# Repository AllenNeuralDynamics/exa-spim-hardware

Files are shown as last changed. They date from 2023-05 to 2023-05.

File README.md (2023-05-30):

# exa-spim-hardware
Hardware files for the ExA-SPIM microscope system

## Description
This repository contains CAD (Solidworks) files for the ExA-SPIM microscope system. Files are organized in directories for each vendor, with subassemblies for various parts of the microscope. A bill of materials (BOM) is also provided.

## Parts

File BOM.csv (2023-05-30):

ITEM NO. | PART NUMBER | DESCRIPTION | QTY.
1 | table_B3648G |  | 1
2 | rail_XT95-1000 |  | 2
3 | rail_XT95-500 |  | 4
4 | rail_clamp_XT95P13 |  | 10
5 | rail_plate_XT95EC1 |  | 6
6 | post_RS6 |  | 4
7 | post_RS1P |  | 4
8 |  |  | 1
9 | board_L490 |  | 1
10 | rail_carriage_XT95RC1 |  | 11
11 |  |  | 1
12 | veo_lens |  | 1
13 | veo_VJD5.0X-151M-X-Y T_V14 |  | 1
14 | clamp_PF85B |  | 1
15 | post_RSH1.5 |  | 1
16 | rail_plate_XT95P12 |  | 3
17 | post_RS3 |  | 5
18 | rail_positioner_XT95N |  | 1
19 | adapter_VJD5.0X MODULE_VNP-604MX_ADAPTER |  | 1
20 | chamber |  | 1
21 | filter |  | 1
22 | ring_SM45RR |  | 1
23 | window |  | 1
24 | window_66191 |  | 1
25 | ring_SM2RR |  | 1
26 | 2958N16 | Sealing Plug | 2
27 | 7610N136 | Universal-Thread Push-to-Connect Tube Fitting | 1
28 | 3-290845 |  | 1
29 | 3-290846 |  | 1
30 | 3-290847 |  | 1
31 | 3-292353 |  | 1
32 | 3-292316 |  | 1
33 | 8-7711 |  | 3
34 | navitar_cap |  | 1
35 | navitar_adapter |  | 1
36 | navitar_window |  | 1
37 | kinematic_KCB2EC |  | 3
38 | cage_LCP30 |  | 2
39 | cage_LCP01 |  | 5
40 | kinematic_CXY2 |  | 6
41 | cage_LCP33 |  | 1
42 | kinematic_KCB1EC |  | 3
43 | kinematic_CXY1A |  | 1
44 | mirror_BBE1-E02 |  | 3
45 | mirror_BBE2-E02 |  | 3
46 | cage_LCP08 |  | 2
47 | lens_ACT508-300-A-ML |  | 1
48 | plate_CP08 |  | 1
49 | iris_SM1D12C |  | 1
50 | cage_CP33 |  | 1
51 | rod_ER2 |  | 12
52 | rod_ER12 |  | 12
53 | post_PH2 |  | 5
54 | post_TR3 |  | 4
55 | post_PH1.5 |  | 2
56 | post_TR1 |  | 4
57 | post_PH1 |  | 3
58 | tube_SM2L05 |  | 1
59 | lens_ACT508-200-A |  | 1
60 | post_TR1.5 |  | 1
61 | rod_ER6 |  | 12
62 | rod_ER3 |  | 4
63 | mount_SM1P1 |  | 1
64 | mount_SM2A6 |  | 1
65 | etl_EL-16-40-TC-VIS-20D-C |  | 1
66 | mount_LRM1 |  | 1
67 | mount_SM1A11 |  | 1
68 | mount_SM1T2 |  | 1
69 | Shibuya_HLB_5X |  | 1
70 | mount_SM1A27 |  | 1
71 | post_PH3 |  | 1
72 | post_TR4 |  | 1
73 | post_TR2 |  | 1
74 | mount_AP90L |  | 2
75 | galvo_QS20Y-AG |  | 2
76 | clamp_BA1S |  | 2
77 | rotation_mount_C60-3060-SRS |  | 1
78 | adapter_SM1A10 |  | 1
79 | tube_SM1L05E |  | 1
80 | adapter_SM2A21 |  | 1
81 | galvo_clamp_1 |  | 2
82 | galvo_clamp_2 |  | 2
83 | post_PH30_M |  | 2
84 | lens_LJ1695RM |  | 1
85 | stage_MS-8000 |  | 1
86 | stage_LS-100-FTP |  | 2
87 | insert_I-8001 |  | 1
88 | sample_base_0284-200-04 | Mounting cube bottom base | 1
89 | sample_wall_0284-200-01 | Mounting cube side wall #1 | 2
90 | sample_wall_0284-200-02 | Mounting cube side wall #2 | 2
91 | sample_lid_0284-200-03 | Mounting cube top | 1
92 | u_mount_0284-100-01 |  | 1

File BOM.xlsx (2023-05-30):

ITEM NO. | SOLIDWORKS PART NUMBER | CATALOG | CATALOG PART NUMBER | DESCRIPTION | QTY.
1 | table_B3648G | Thorlabs | B3648G |  | 1
2 | rail_XT95-1000 | Thorlabs | XT95-1000 |  | 2
3 | rail_XT95-500 | Thorlabs | XT95-500 |  | 4
4 | rail_clamp_XT95P13 | Thorlabs | XT95P13 |  | 10
5 | rail_plate_XT95EC1 | Thorlabs | XT95EC1 |  | 6
6 | post_RS6 | Thorlabs | RS6 |  | 4
7 | post_RS1P | Thorlabs | RS1P |  | 4
8 | board_MB624 | Thorlabs | MB624 |  | 1
9 | board_L490 | Thorlabs | L490 |  | 1
10 | rail_carriage_XT95RC1 | Thorlabs | XT95RC1 |  | 11
11 | board_MB424 | Thorlabs | MB424 |  | 1
12 | veo_lens | VEO | veo_lens |  | 1
13 | veo_VJD5.0X-151M-X-Y T_V14 | VEO | veo_VJD5.0X-151M-X-Y T_V14 |  | 1
14 | clamp_PF85B | Thorlabs | PF85B |  | 1
15 | post_RSH1.5 | Thorlabs | RSH1.5 |  | 1
16 | rail_plate_XT95P12 | Thorlabs | XT95P12 |  | 3
17 | post_RS3 | Thorlabs | RS3 |  | 5
18 | rail_positioner_XT95N | Thorlabs | XT95N |  | 1
19 | adapter_VJD5.0X MODULE_VNP-604MX_ADAPTER |  | adapter_VJD5.0X MODULE_VNP-604MX_ADAPTER |  | 1
20 | chamber | CUSTOM | chamber |  | 1
21 | filter |  | filter |  | 1
22 | ring_SM45RR | Thorlabs | SM45RR |  | 1
23 | window |  | window |  | 1
24 | window_66191 |  | window_66191 |  | 1
25 | ring_SM2RR | Thorlabs | SM2RR |  | 1
26 | 2958N16 | McMaster-Carr | 2958N16 | Sealing Plug | 2
27 | 7610N136 | McMaster-Carr | 7610N136 | Universal-Thread Push-to-Connect Tube Fitting | 1
28 | 3-290845 |  | 3-290845 |  | 1
29 | 3-290846 |  | 3-290846 |  | 1
30 | 3-290847 |  | 3-290847 |  | 1
31 | 3-292353 |  | 3-292353 |  | 1
32 | 3-292316 |  | 3-292316 |  | 1
33 | 8_7711 |  | 8_7711 |  | 3
34 | navitar_cap | Navitar | navitar_cap |  | 1
35 | navitar_adapter | Navitar | navitar_adapter |  | 1
36 | navitar_window | Navitar | navitar_window |  | 1
37 | kinematic_KCB2EC | Thorlabs | KCB2EC |  | 3
38 | cage_LCP30 | Thorlabs | LCP30 |  | 2
39 | cage_LCP01 | Thorlabs | LCP01 |  | 5
40 | kinematic_CXY2 | Thorlabs | CXY2 |  | 6
41 | cage_LCP33 | Thorlabs | LCP33 |  | 1
42 | kinematic_KCB1EC | Thorlabs | KCB1EC |  | 3
43 | kinematic_CXY1A | Thorlabs | CXY1A |  | 1
44 | mirror_BBE1-E02 | Thorlabs | BBE1-E02 |  | 3
45 | mirror_BBE2-E02 | Thorlabs | BBE2-E02 |  | 3
46 | cage_LCP08 | Thorlabs | LCP08 |  | 2
47 | lens_ACT508-300-A-ML | Thorlabs | ACT508-300-A-ML |  | 1
48 | plate_CP08 | Thorlabs | CP08 |  | 1
49 | iris_SM1D12C | Thorlabs | SM1D12C |  | 1
50 | cage_CP33 | Thorlabs | CP33 |  | 1
51 | rod_ER2 | Thorlabs | ER2 |  | 12
52 | rod_ER12 | Thorlabs | ER12 |  | 12
53 | post_PH2 | Thorlabs | PH2 |  | 5
54 | post_TR3 | Thorlabs | TR3 |  | 4
55 | post_PH1.5 | Thorlabs | PH1.5 |  | 2
56 | post_TR1 | Thorlabs | TR1 |  | 4
57 | post_PH1 | Thorlabs | PH1 |  | 3
58 | tube_SM2L05 | Thorlabs | SM2L05 |  | 1
59 | lens_ACT508-200-A | Thorlabs | ACT508-200-A |  | 1
60 | post_TR1.5 | Thorlabs | TR1.5 |  | 1
61 | rod_ER6 | Thorlabs | ER6 |  | 12
62 | rod_ER3 | Thorlabs | ER3 |  | 4
63 | mount_SM1P1 | Thorlabs | SM1P1 |  | 1
64 | mount_SM2A6 | Thorlabs | SM2A6 |  | 1
65 | etl_EL-16-40-TC-VIS-20D-C |  | etl_EL-16-40-TC-VIS-20D-C |  | 1
66 | mount_LRM1 | Thorlabs | LRM1 |  | 1
67 | mount_SM1A11 | Thorlabs | SM1A11 |  | 1
68 | mount_SM1T2 | Thorlabs | SM1T2 |  | 1
69 | Shibuya_HLB_5X |  | Shibuya_HLB_5X |  | 1
70 | mount_SM1A27 | Thorlabs | SM1A27 |  | 1
71 | post_PH3 | Thorlabs | PH3 |  | 1
72 | post_TR4 | Thorlabs | TR4 |  | 1
73 | post_TR2 | Thorlabs | TR2 |  | 1
74 | mount_AP90L | Thorlabs | AP90L |  | 2
75 | galvo_QS20Y-AG | Thorlabs | QS20Y-AG |  | 2
76 | clamp_BA1S | Thorlabs | BA1S |  | 2
77 | rotation_mount_C60-3060-SRS | Thorlabs | C60-3060-SRS |  | 1
78 | adapter_SM1A10 | Thorlabs | SM1A10 |  | 1
79 | tube_SM1L05E | Thorlabs | SM1L05E |  | 1
80 | adapter_SM2A21 | Thorlabs | SM2A21 |  | 1
81 | galvo_clamp_1 | Custom | galvo_clamp_1 |  | 2
82 | galvo_clamp_2 | Custom | galvo_clamp_2 |  | 2
83 | post_PH30_M | Thorlabs | PH30_M |  | 2
84 | lens_LJ1695RM | Thorlabs | LJ1695RM |  | 1
85 | stage_MS-8000 | ASI | MS-8000 |  | 1
86 | stage_LS-100-FTP | ASI | LS-100-FTP |  | 2
87 | insert_I-8001 | ASI | I-8001 |  | 1
88 | sample_base_0284-200-04 |  | sample_base_0284-200-04 | Mounting cube bottom base | 1
89 | sample_wall_0284-200-01 |  | sample_wall_0284-200-01 | Mounting cube side wall #1 | 2
90 | sample_wall_0284-200-02 |  | sample_wall_0284-200-02 | Mounting cube side wall #2 | 2
91 | sample_lid_0284-200-03 |  | sample_lid_0284-200-03 | Mounting cube top | 1
92 | u_mount_0284-100-01 |  | u_mount_0284-100-01 |  | 1

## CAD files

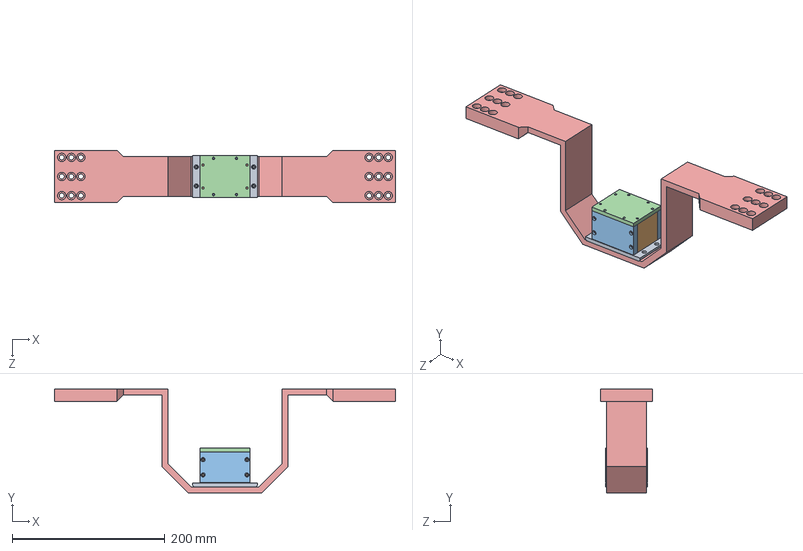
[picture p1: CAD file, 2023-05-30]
subasm_sample_holder.SLDASM
446.0 x 136.0 x 68.6 mm
sample_base_0284-200-04
sample_wall_0284-200-01 x 2
sample_wall_0284-200-02 x 2
u_mount_0284-100-01

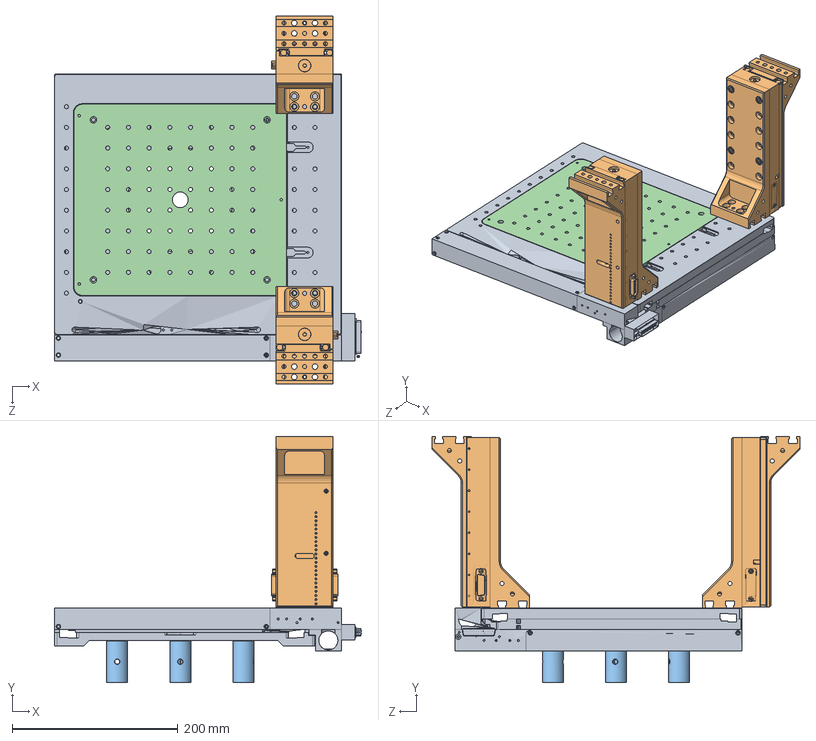
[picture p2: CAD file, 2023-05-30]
subasm_stages.SLDASM
370.5 x 297.4 x 444.1 mm
stage_MS-8000
stage_LS-100-FTP x 2
post_RS2 x 4
insert_I-8001

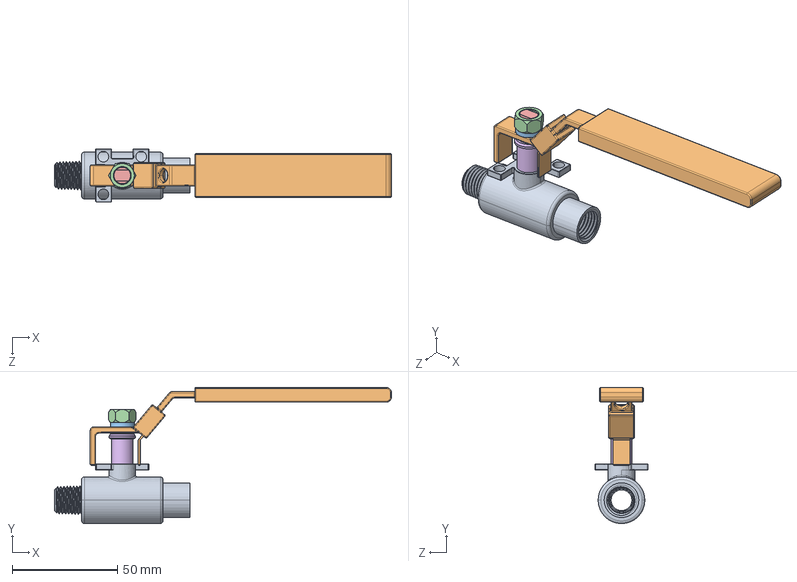
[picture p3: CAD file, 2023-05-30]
grainger/keckley_BVS2MFFSSRGSL-050.SLDASM
160.3 x 64.7 x 25.4 mm
B247A_X_0_1_4_INCH.stp
B247_B242_A_X_0_LH_1_4_INCH.stp
B247A_B242_B_X_0_WASH_1_4_INCH.stp
B247_B242_A_X_0_NUT_1_4_INCH.stp
B247_B242_A_X_0_STEM_1_4_INCH.stp
B247A_B242_A_X_0_GLAND_1_4_INCH.stp

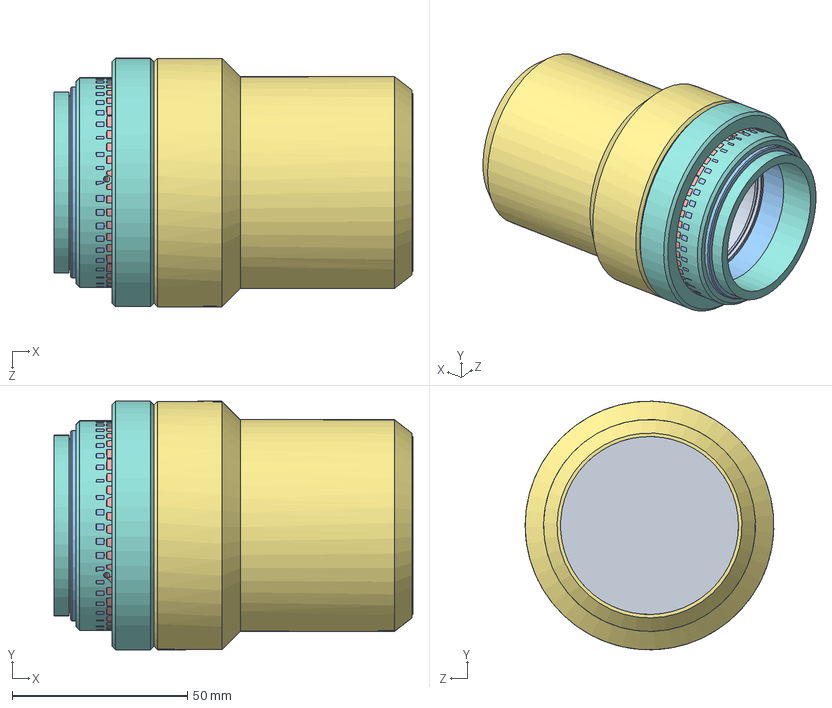
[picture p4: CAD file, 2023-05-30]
navitar/navitar_290419.SLDASM
102.5 x 71.0 x 71.0 mm
navitar_cap
navitar_adapter
navitar_window

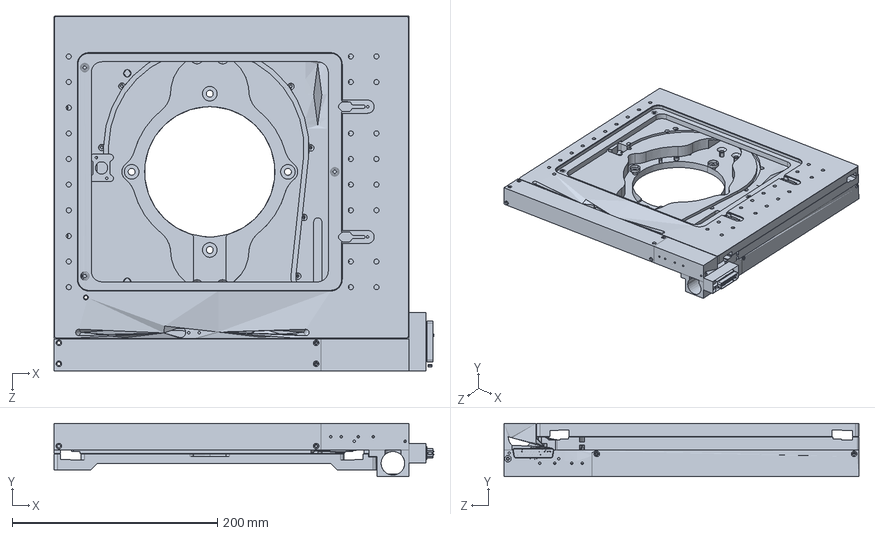
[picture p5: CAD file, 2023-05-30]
ASI/stage_MS-8000.SLDPRT
370.5 x 51.8 x 346.1 mm

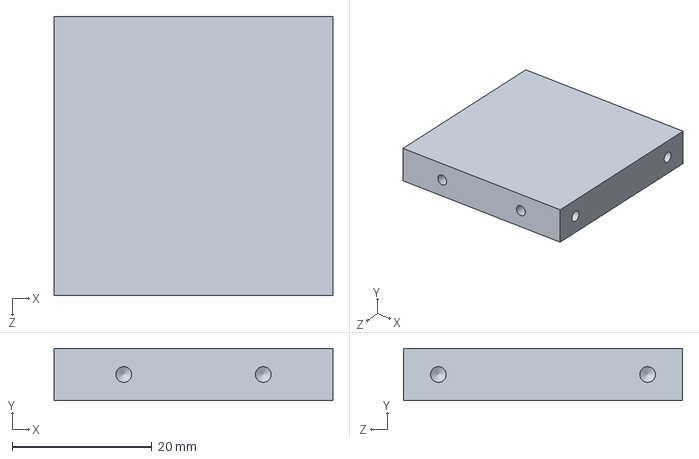
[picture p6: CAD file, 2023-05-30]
custom/sample_wall_0284-200-01.SLDPRT
40.0 x 7.50 x 40.0 mm

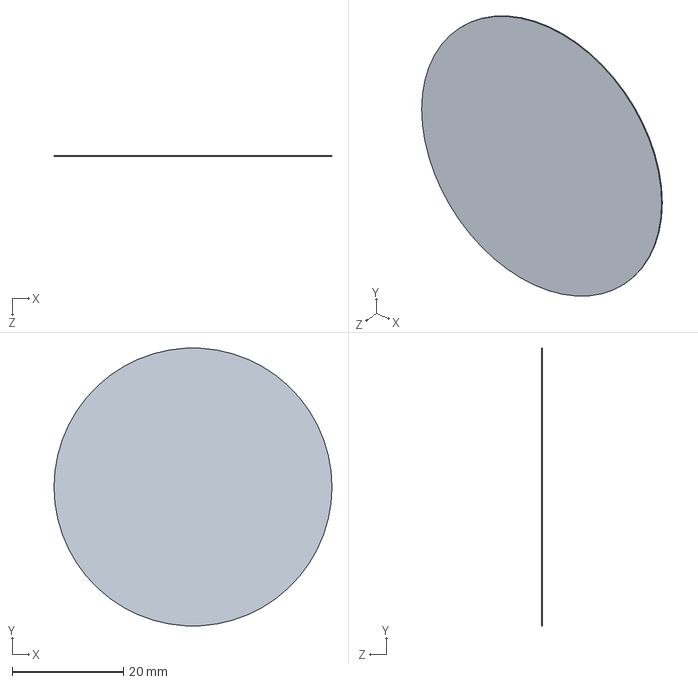
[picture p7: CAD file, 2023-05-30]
edmund/window_66191.SLDPRT
50.0 x 49.9 x 0.2 mm

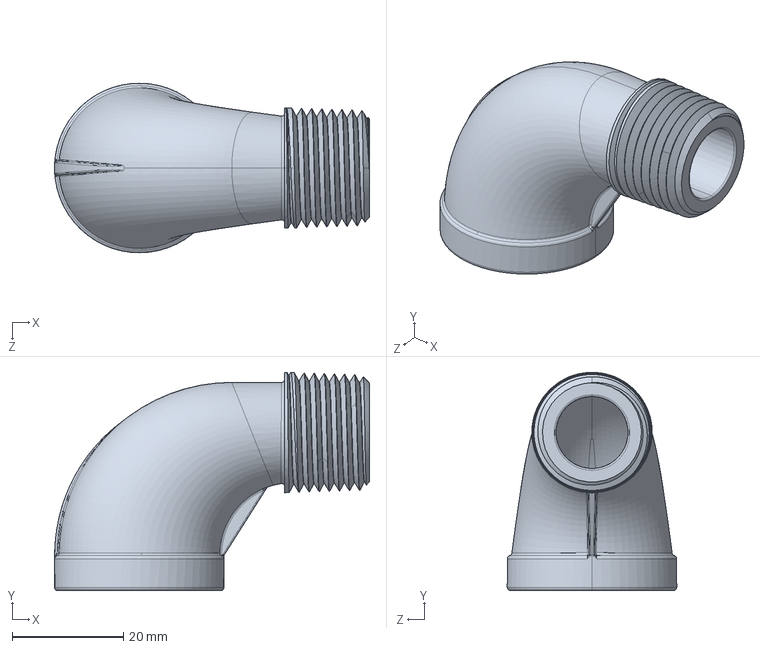
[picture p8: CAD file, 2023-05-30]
grainger/6JM42.SLDPRT
56.6 x 39.3 x 30.5 mm

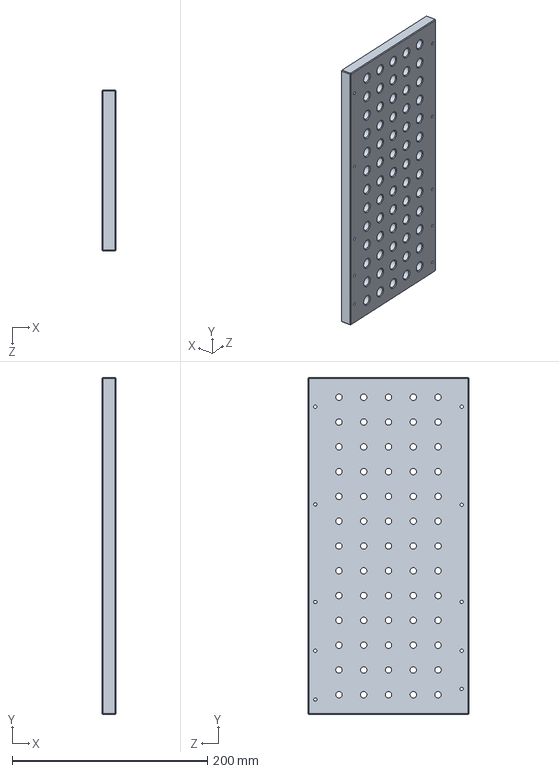
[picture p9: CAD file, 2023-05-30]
veo/adapter_VJD5.0X MODULE_VNP-604MX_ADAPTER.SLDPRT
14.7 x 345.3 x 165.0 mm

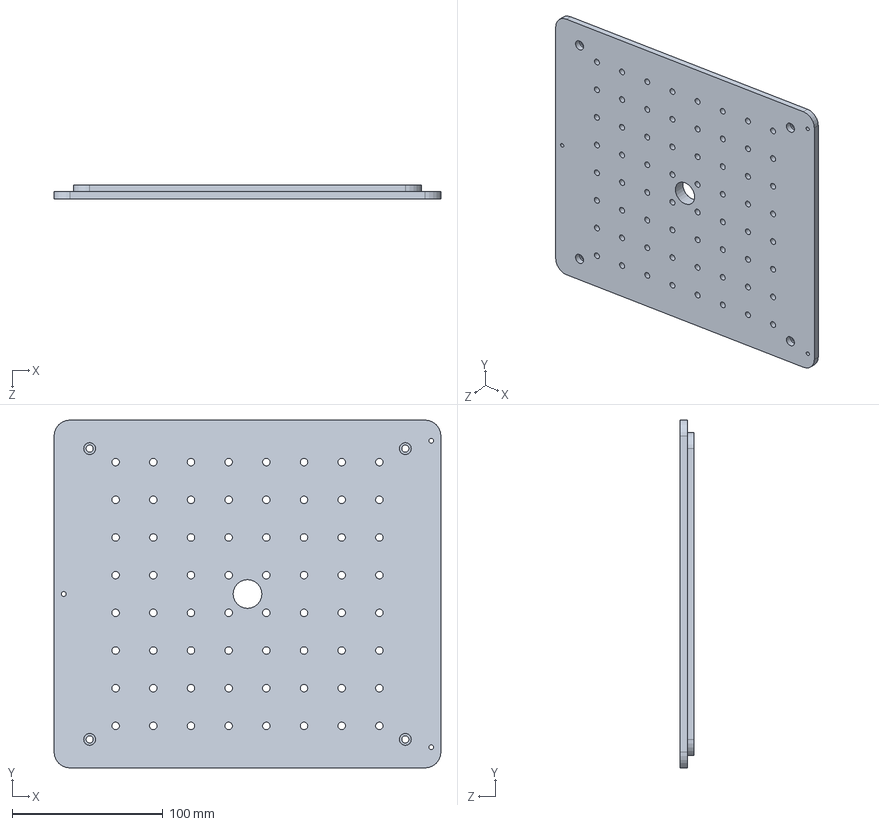
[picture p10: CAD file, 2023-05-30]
ASI/insert_I-8001.SLDPRT
256.8 x 230.9 x 9.53 mm

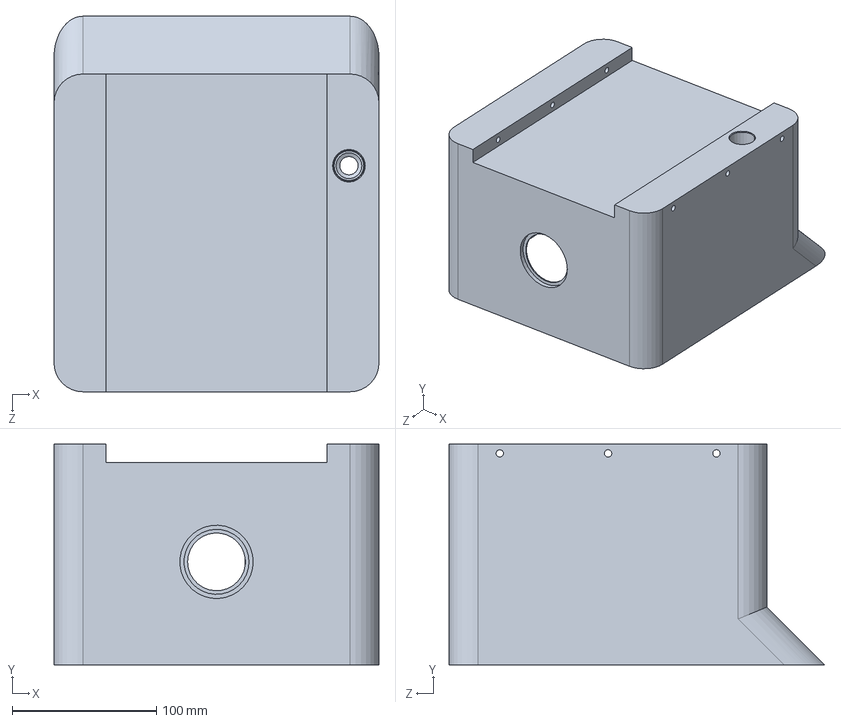
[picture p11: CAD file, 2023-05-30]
custom/chamber.SLDPRT
225.0 x 152.7 x 260.0 mm

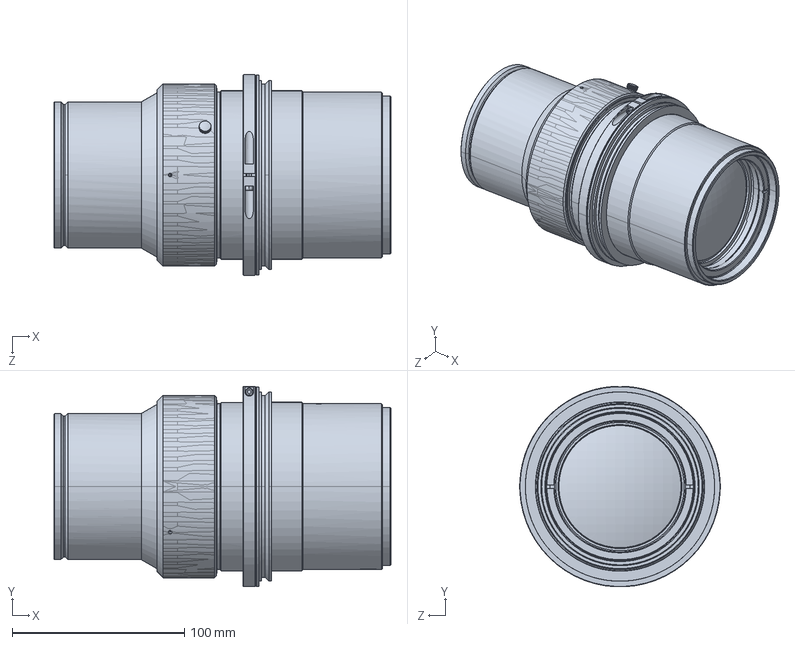
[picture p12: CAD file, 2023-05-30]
veo/veo_lens.SLDPRT
195.8 x 116.5 x 116.6 mm

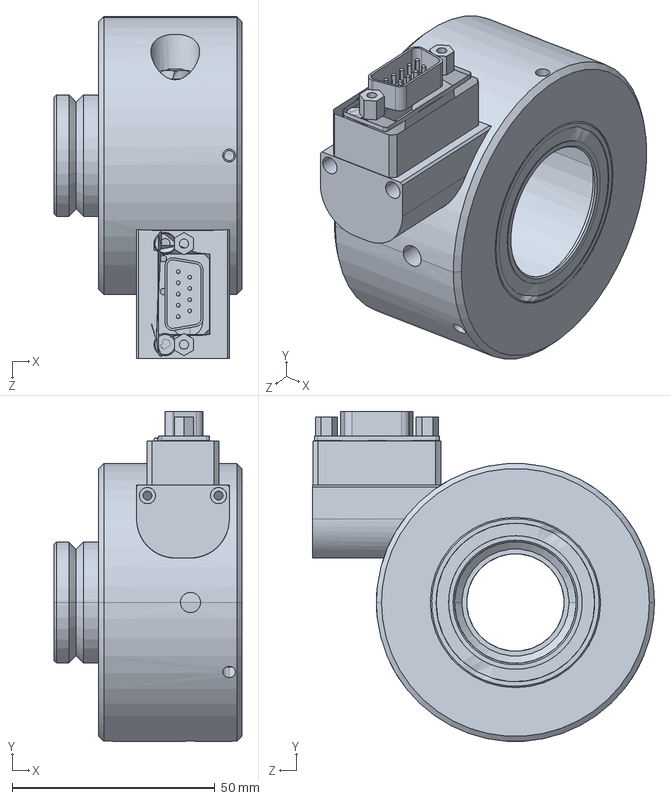
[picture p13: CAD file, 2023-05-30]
ASI/rotation_mount_C60-3060-SRS.SLDPRT
46.4 x 81.4 x 84.3 mm

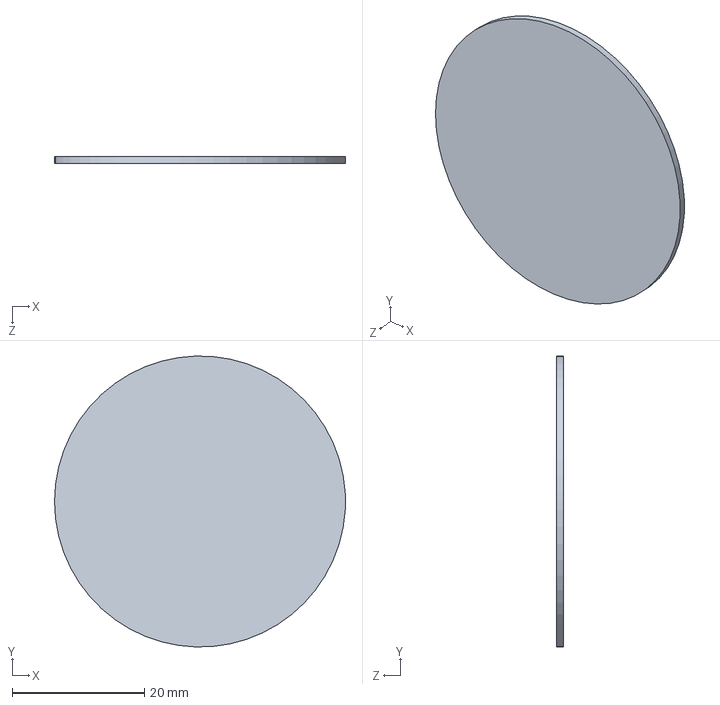
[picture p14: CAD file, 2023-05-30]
custom/filter.SLDPRT
44.0 x 44.0 x 1.00 mm

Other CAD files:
navitar/3-290846.SLDPRT
grainger/1LTV6.SLDPRT
navitar/3-292353.SLDPRT
ASI/stage_LS-100-FTP.SLDPRT
custom/Shibuya_HLB_5X.SLDPRT
custom/galvo_clamp_1.SLDPRT
custom/galvo_clamp_2.SLDPRT
custom/galvo_holder V2.SLDPRT
custom/galvo_holder.SLDPRT
custom/laser_box.SLDPRT
custom/sample_base_0284-200-04.SLDPRT
custom/sample_lid_0284-200-03.SLDPRT
custom/sample_wall_0284-200-02.SLDPRT
custom/u_mount_0284-100-01.SLDPRT
custom/window.SLDPRT
mcmaster/PVCtubing_5233K58.SLDPRT
mcmaster/maleNPT_4548K171.SLDPRT
mcmaster/plug_2958N16.SLDPRT
mcmaster/reducer_4452K165.SLDPRT
mcmaster/tube fitting_7610N136.SLDPRT
mcmaster/tube_fitting_7610N123.SLDPRT
mcmaster/valve_4072T55.SLDPRT
mcmaster/valve_47205K12_PVC On Off Valve.SLDPRT
mcmaster/valve_7952K36_Compact PVC On Off Elbow Valve for Water.SLDPRT
navitar/3-290845.SLDPRT
navitar/3-290847.SLDPRT
navitar/3-292316.SLDPRT
navitar/8-7711.SLDPRT
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
